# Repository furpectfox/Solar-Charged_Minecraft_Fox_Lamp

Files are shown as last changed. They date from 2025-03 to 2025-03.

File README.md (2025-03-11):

# Solar-Charged Minecraft Fox Lamp
***Description***: This sleep lamp is powered by two Ni-Cd cells wired in series for a total of 2.4V and can be charged using a small solar panel. The Red and Green LEDs of an RGB LED are used to produce the orange light, consuming ~30mA combined.

***Charging***: A transistor-based constant current circuit trickle-charges the two Ni-Cd cells at 60mA using a 9V solar panel.

***Usage***: The lamp provides approximately 16 hours of usable light on a full charge.

## [Schematic](schematic.pdf)

## PCB
***[PCB was etched at home using a PCB Pen Plotter attachment](https://github.com/furpectfox/PCB_Trace_Plotter)**  

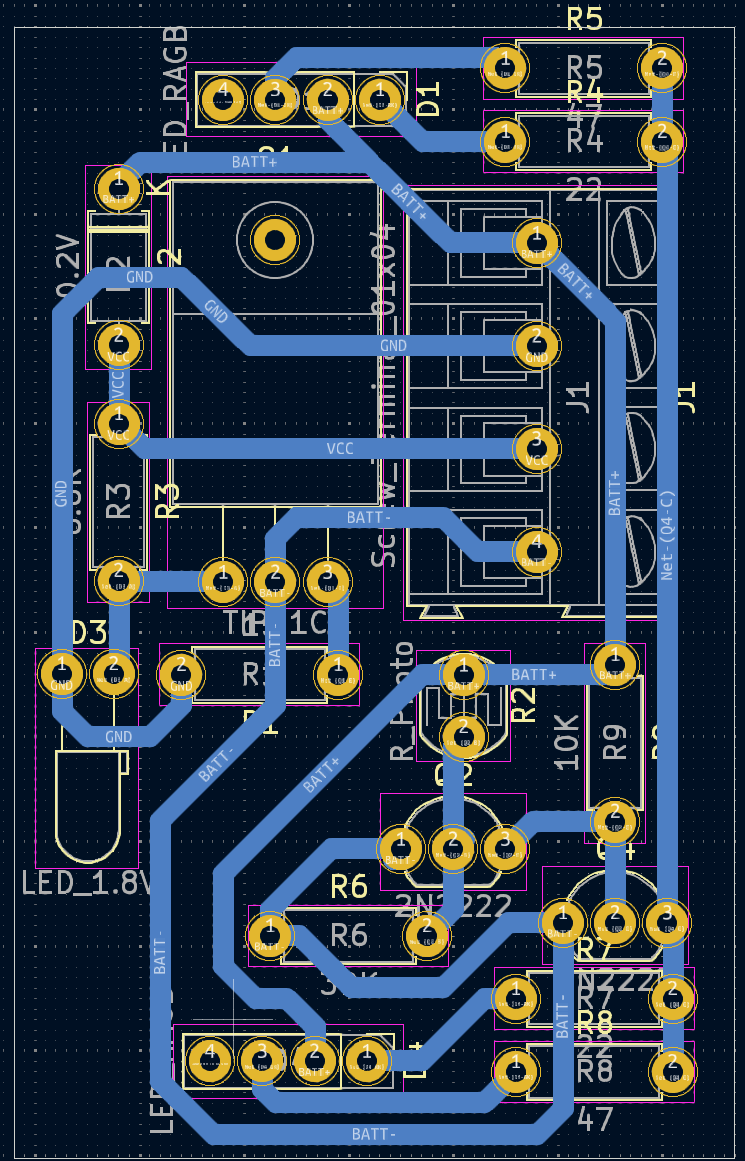
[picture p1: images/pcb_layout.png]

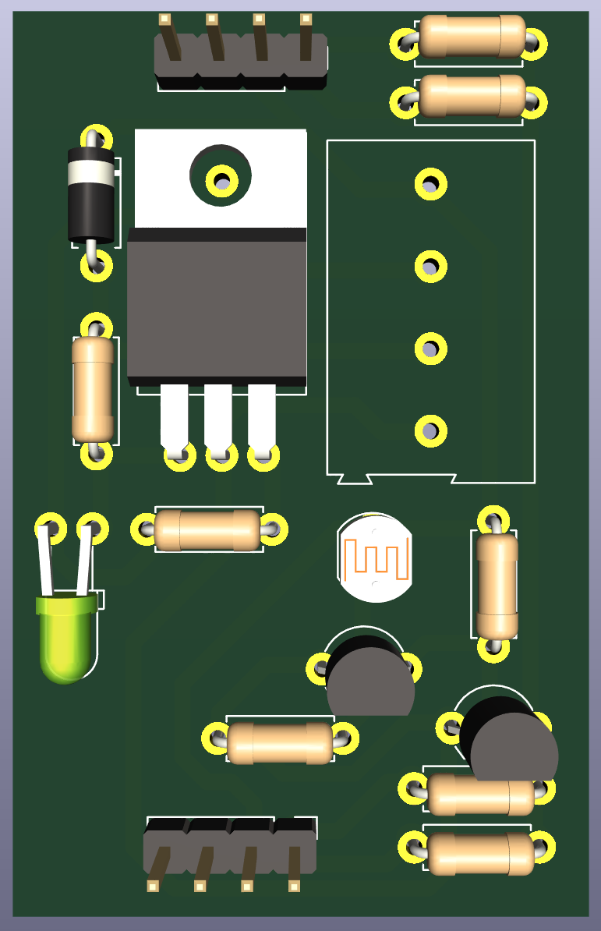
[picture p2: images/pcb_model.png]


## Finish
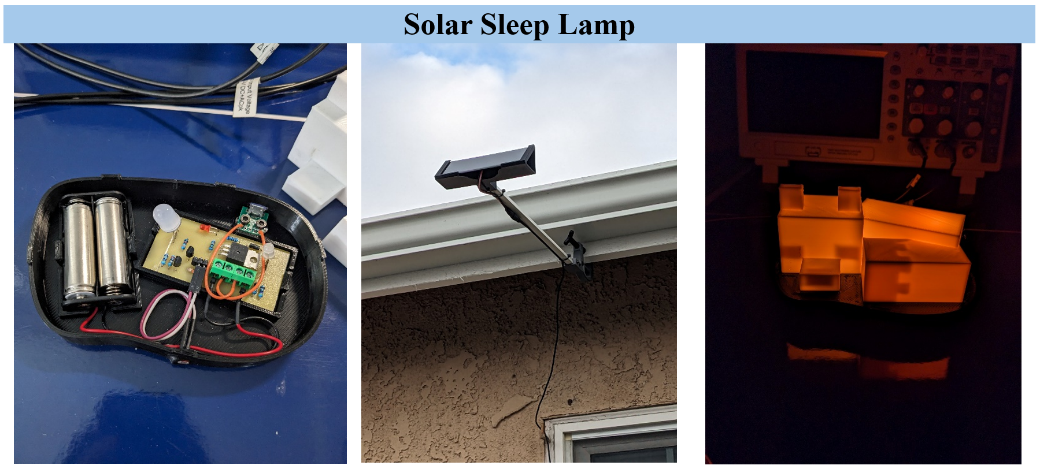
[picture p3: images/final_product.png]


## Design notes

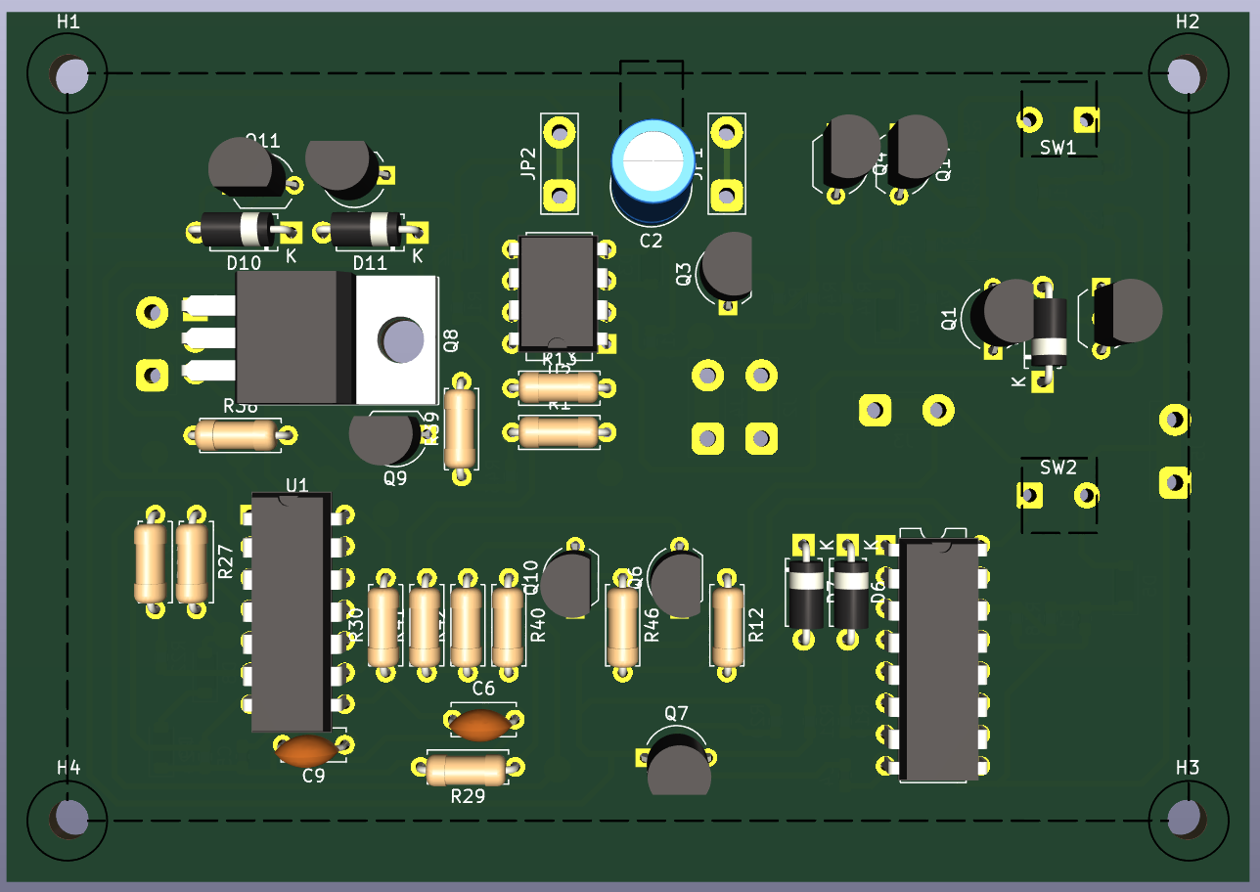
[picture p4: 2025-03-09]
images/pcb(front).png

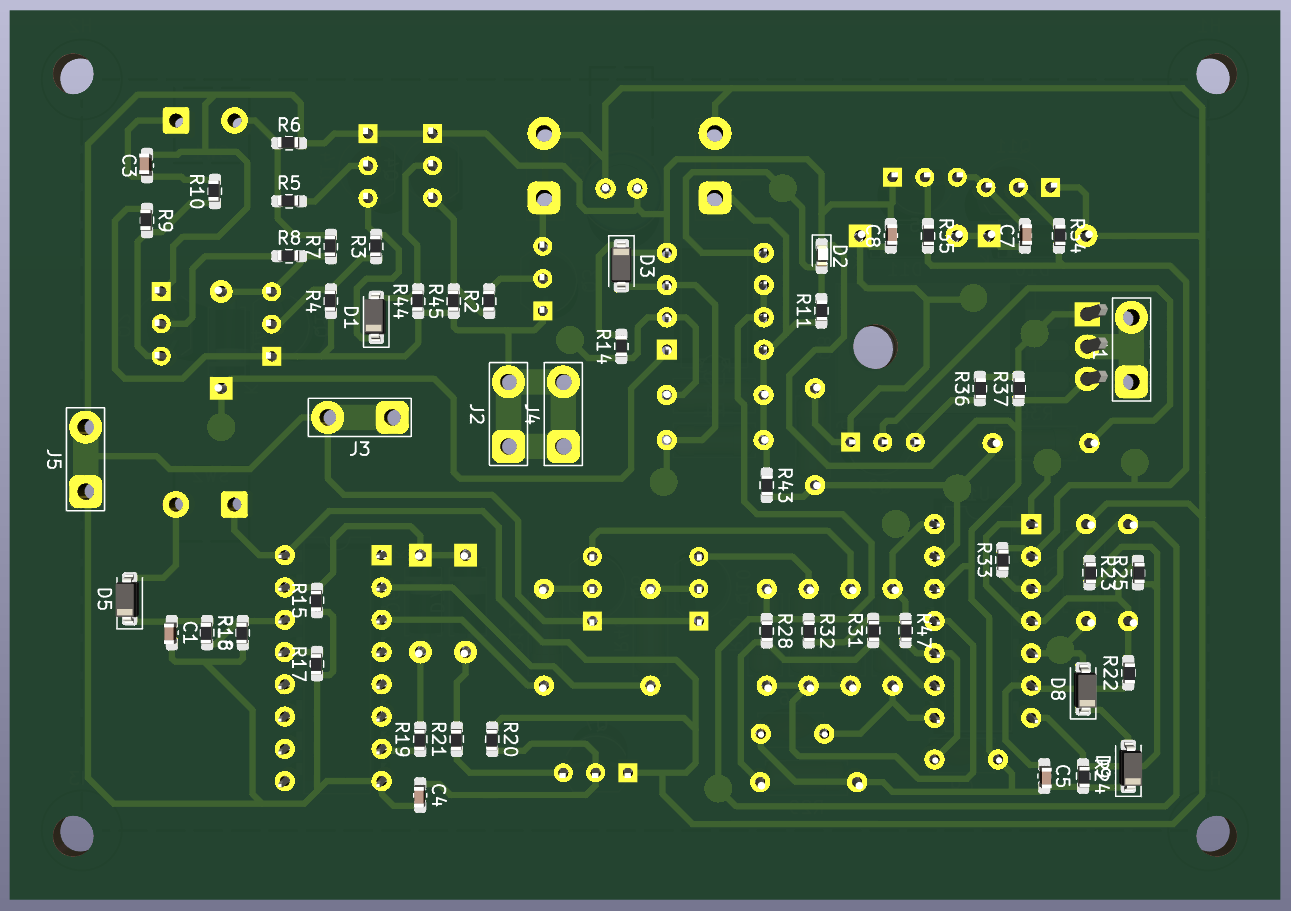
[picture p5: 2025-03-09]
images/pcb(back).png

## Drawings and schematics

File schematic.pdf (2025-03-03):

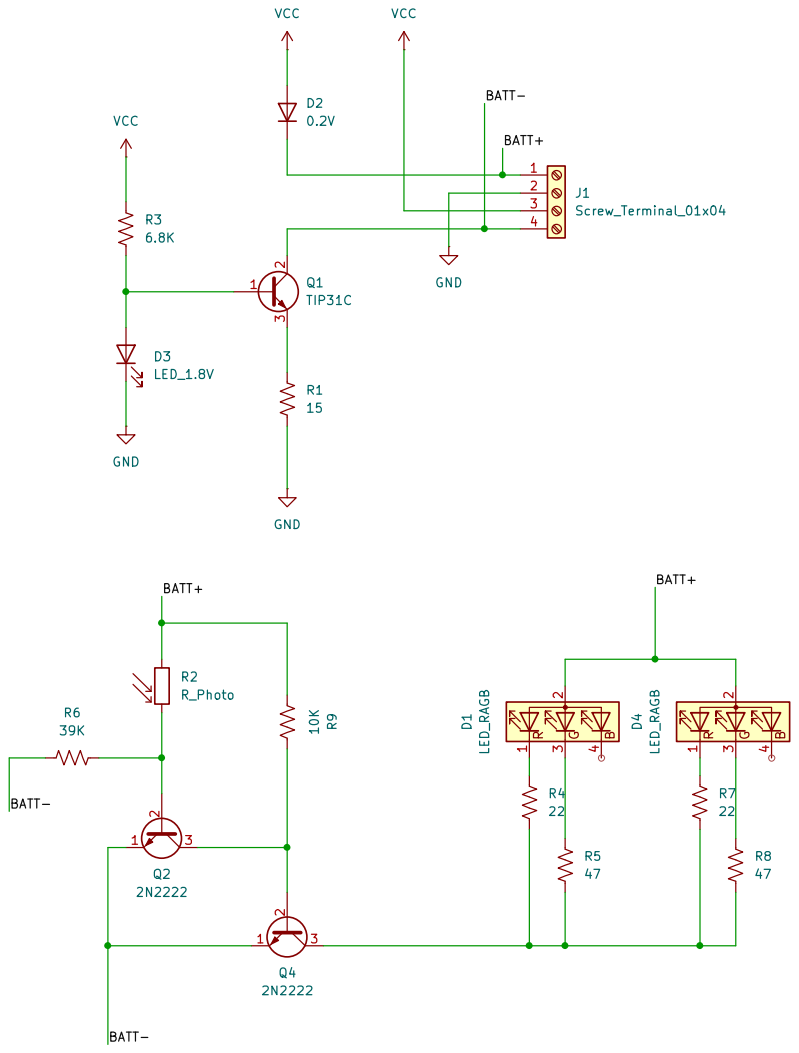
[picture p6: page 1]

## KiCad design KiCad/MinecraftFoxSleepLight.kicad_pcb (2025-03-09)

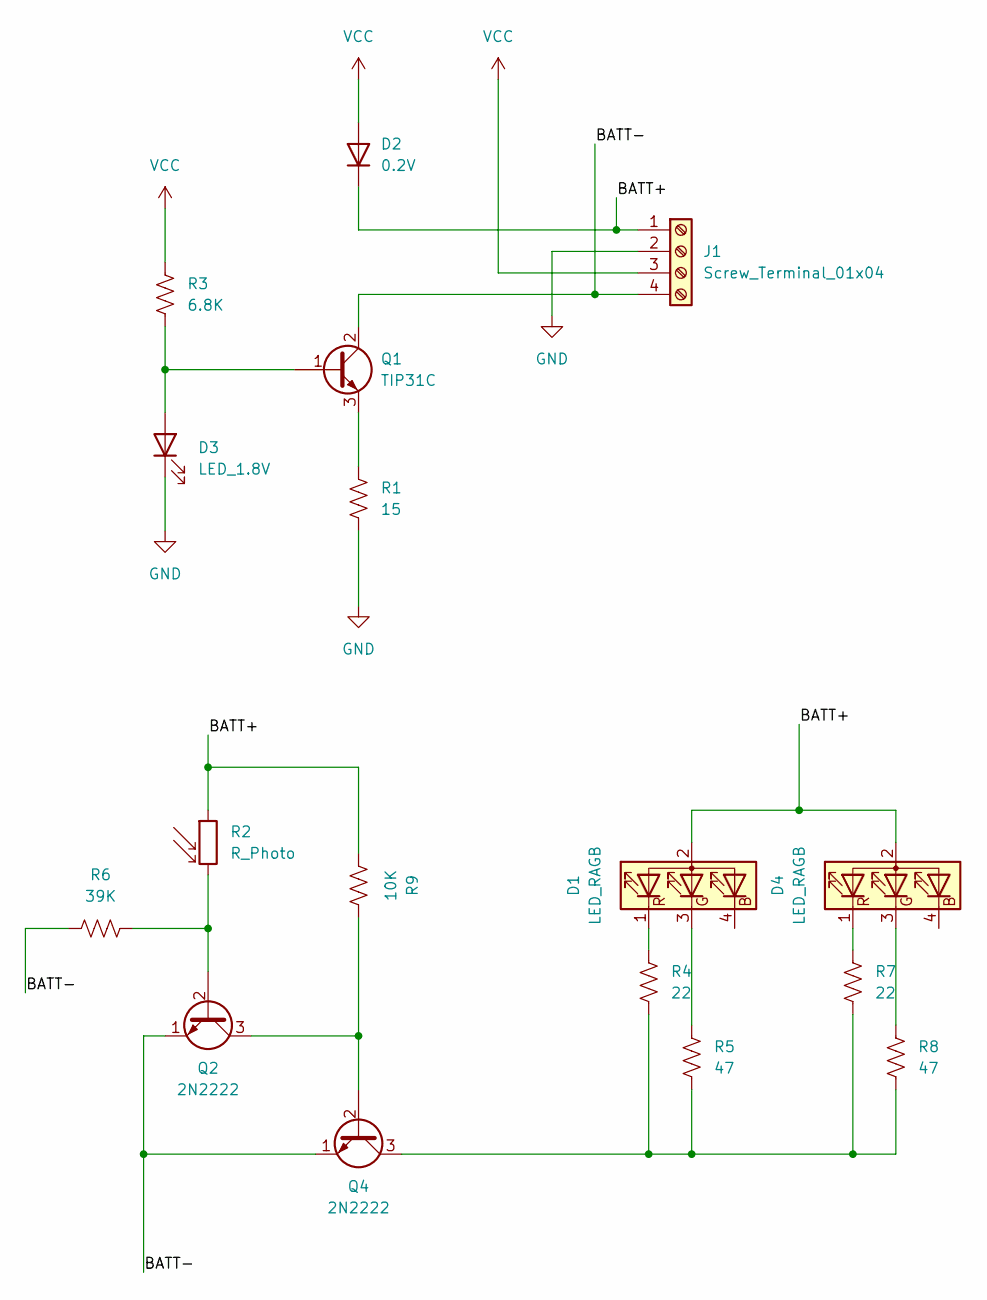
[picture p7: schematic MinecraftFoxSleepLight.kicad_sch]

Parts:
D1, D4: LED_RAGB; PinHeader_1x04_P2.54mm_Vertical
D2: 0.2V; D_A-405_P7.62mm_Horizontal
D3: LED_1.8V; LED_D3.0mm_Horizontal_O3.81mm_Z2.0mm
J1: Screw_Terminal_01x04; TerminalBlock_Altech_AK300-4_P5.00mm
Q1: TIP31C; TO-220-3_Horizontal_TabDown
Q2, Q4: 2N2222; TO-92_Inline_Wide
R1: 15; R_Axial_DIN0207_L6.3mm_D2.5mm_P7.62mm_Horizontal
R2: R_Photo; R_LDR_5.0x4.1mm_P3mm_Vertical
R3: 6.8K; R_Axial_DIN0207_L6.3mm_D2.5mm_P7.62mm_Horizontal
R4, R7: 22; R_Axial_DIN0207_L6.3mm_D2.5mm_P7.62mm_Horizontal
R5, R8: 47; R_Axial_DIN0207_L6.3mm_D2.5mm_P7.62mm_Horizontal
R6: 39K; R_Axial_DIN0207_L6.3mm_D2.5mm_P7.62mm_Horizontal
R9: 10K; R_Axial_DIN0207_L6.3mm_D2.5mm_P7.62mm_Horizontal

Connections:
/BATT+: D1.2 (A), D2.1 (K), D4.2 (A), J1.1, R2.1, R9.1
/BATT-: J1.4, Q1.2 (C), Q2.1 (E), Q4.1 (E), R6.1
GND: D3.1 (K), J1.2, R1.2
unnamed: D1.3 (GK), R5.1
unnamed: D1.1 (RK), R4.1
unnamed: D3.2 (A), Q1.1 (B), R3.2
unnamed: D4.3 (GK), R8.1
unnamed: D4.1 (RK), R7.1
unnamed: Q1.3 (E), R1.1
unnamed: Q2.2 (B), R2.2, R6.2
unnamed: Q2.3 (C), Q4.2 (B), R9.2
unnamed: Q4.3 (C), R4.2, R5.2, R7.2, R8.2
VCC: D2.2 (A), J1.3, R3.1

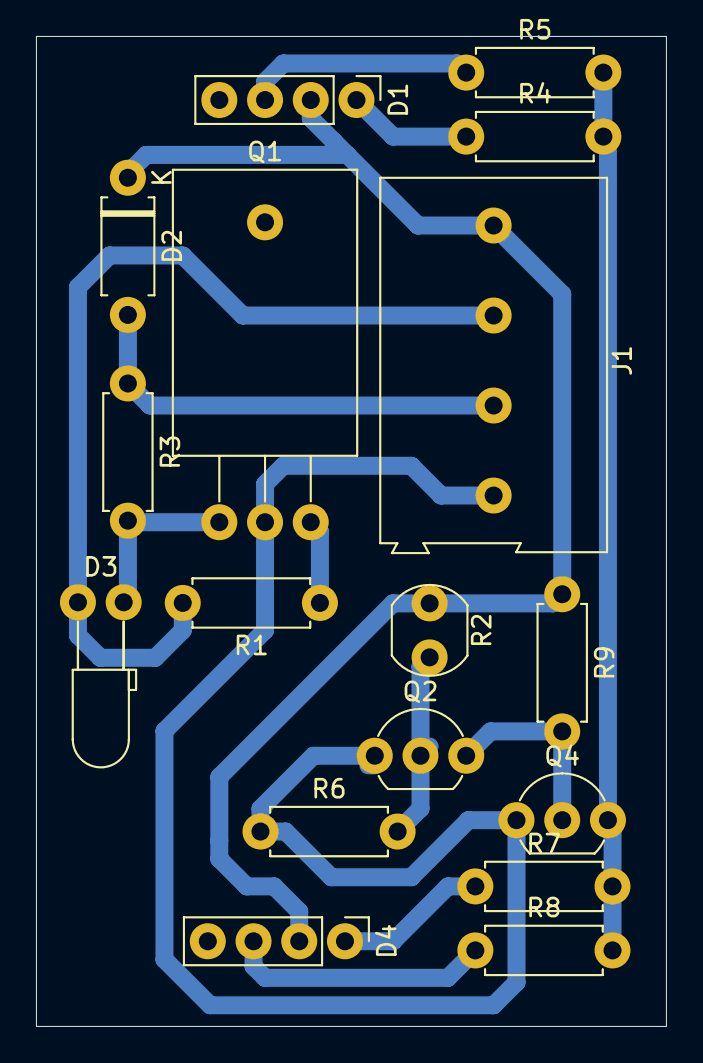
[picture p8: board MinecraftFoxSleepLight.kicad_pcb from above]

Board: 2 copper layers, 35.0 x 55.0 mm, 17 parts (0 on the bottom side), 13 nets.

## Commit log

2024-07-24 add schematic and pcb layout
    [Ni-Cd_Solar_Trickle_Charger.kicad_pcb, Ni-Cd_Solar_Trickle_Charger.kicad_sch]
2025-03-03 update schematic
    [Ni-Cd_Solar_Trickle_Charger.kicad_pcb, Ni-Cd_Solar_Trickle_Charger.kicad_sch]
2025-03-09 add KiCad folder
    [MinecraftFoxSleepLight.kicad_pcb, MinecraftFoxSleepLight.kicad_sch]
2025-03-09 add file to KiCad folder
